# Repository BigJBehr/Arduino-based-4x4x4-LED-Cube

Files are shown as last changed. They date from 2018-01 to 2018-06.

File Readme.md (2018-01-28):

# Arduino based 4x4x4 LED Cube
This project is for a 4x4x4 cube of APA106 tri-color, addressable LEDs. The code was developed using the Arduino IDE. The Adafruit NeoPixel Arduino library and the Arduino Encoder library are required. You can install both libraries using the Library Manager in the Arduino IDE.

The code is for a project that was developed for the Arduino contest on the Instructables web site. There you can find detailed instuctions on how to assemble one for yourself. Follow this link; https://www.instructables.com/id/Cubic_Art/.

# The CubeObject folder has all of the Arduino source files. 
The project was written in C++. Each class used has its own files (.cpp & .h).

# The 3D Parts folder has the OpenSCAD source files and .STL files of all of the 3D printed parts of the project. 
The files are;
    LedCubeJig.stl file is used to 3D print a bending/soldering jig for bending the leads of the LEDs and soldering them together to made the layers of the LED cube.
    spacer.stl file is used to 3D print the spacers that are used to hold the LED layers together while you solder the buses.
    All.stl file is used to 3d print all of the parts for the LED cube.
    Bottom.stl is for 3D printing just the base or bottom of the LED cube.
    Top.stl is for 3D printing the top of the LED cube and the four LED cube holders.
    Knob.stl will 3D print a knob for the rotary encoder in the shape of an orb.

The LedCub.scad file has selections that can be set to true or false to determine what type of Arduino you are using (R3 compatible, ProMini or Nano), what type of USB socket is used and wheather you require a power switch or not. The file usses the software decorator patttern to create the top and base of the LED cube.

# The Diagrams folder has PDF wiring diagrams and a drawing you can print to help make a jig for soldering the LEDs into the layers that make up the cube.
 The preffered mthod is to use the 3D printed jig, but not everyone has access to a 3D printer. The wiring diagram to use is based on the Arduino type and how you choose to use it.
    Nano Wiring .pdf
    R3 Wiring.pdf
    Wiring.pdf
    SpacingJig.pdf is for making a paper diagram for building a soldering jig out of a block of wood.

Enjoy

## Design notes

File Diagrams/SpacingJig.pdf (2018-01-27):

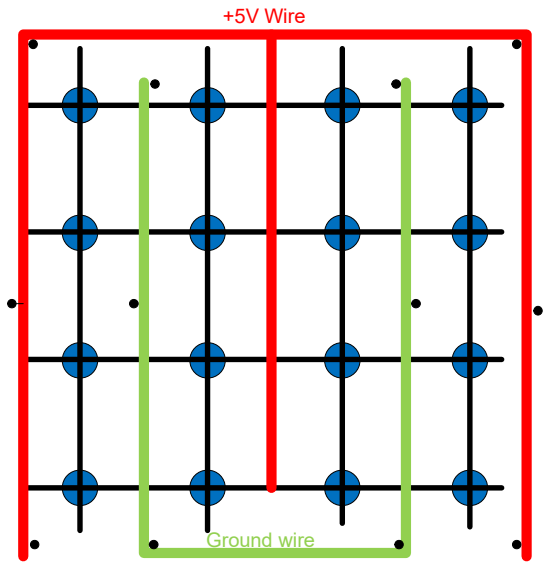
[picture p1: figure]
+5V Wire; Ground wire

# Front

Drill 5mm (7/32) holes in the center of the blue circles.

Bend a piece of the bare 22 awg wire to make the +5V Wire around the outside.

Add a piece of bare 22 awg wire down the center as shown. Solder it to the outside +5V Wire.

Bend a piece of the bare 22 awg wire to make the inner Ground Wire. The Ground Wire should be centered between the LEDs.

Note: Do not put the +5V and Ground Wires up against the LEDs. Leave some space for the LEDs on the ends to connect to each other.

# LED Spacing and Wiring Jig

Driving brads or nails in where the black circles are will aide in bending the 22 awg wires and help to keep them in place. Cut the heads off the nails after driving them in, leaving about ¼” exposed.

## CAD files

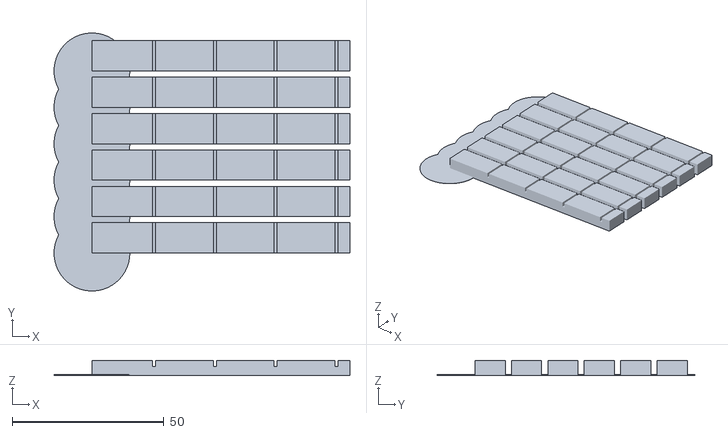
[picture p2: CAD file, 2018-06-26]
3D Parts/LedCubeSpacers.stl
97.5 x 85.0 x 5.00

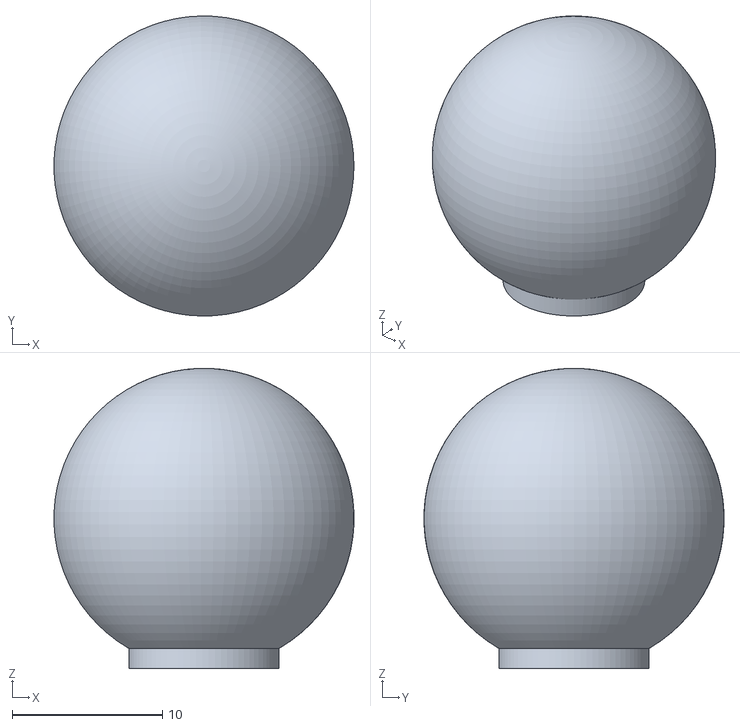
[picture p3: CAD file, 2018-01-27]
3D Parts/Knob.stl
20.0 x 20.0 x 20.0

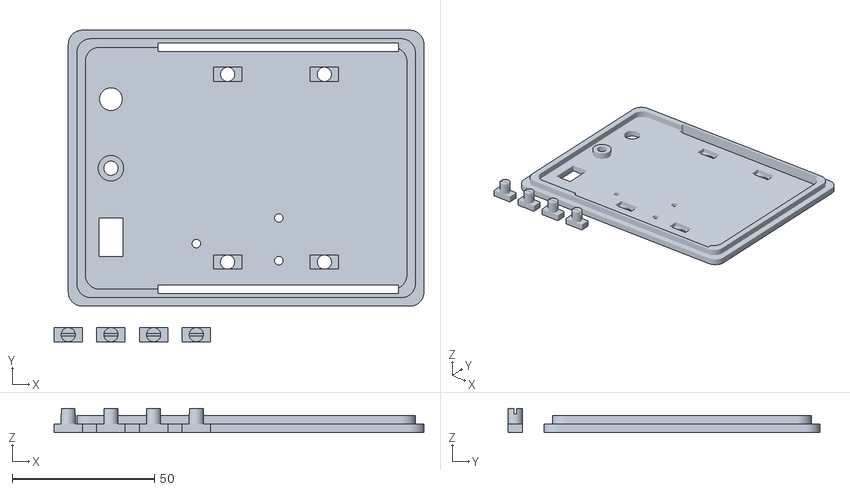
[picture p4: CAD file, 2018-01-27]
3D Parts/Top.stl
130.0 x 109.5 x 8.50

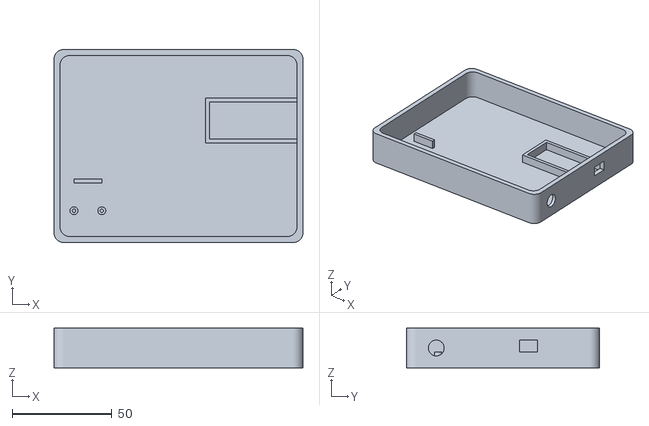
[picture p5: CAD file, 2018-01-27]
3D Parts/Bottom.stl
125.0 x 97.0 x 20.0

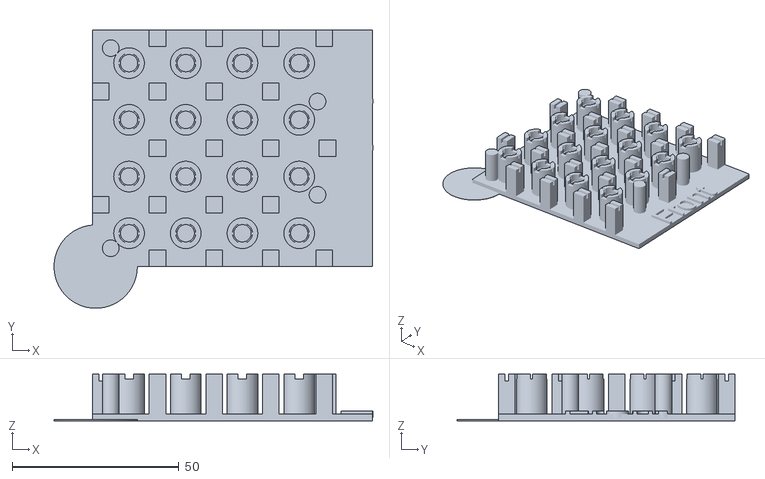
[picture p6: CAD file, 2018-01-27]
3D Parts/LedCubeJig.stl
95.6 x 83.5 x 14.0

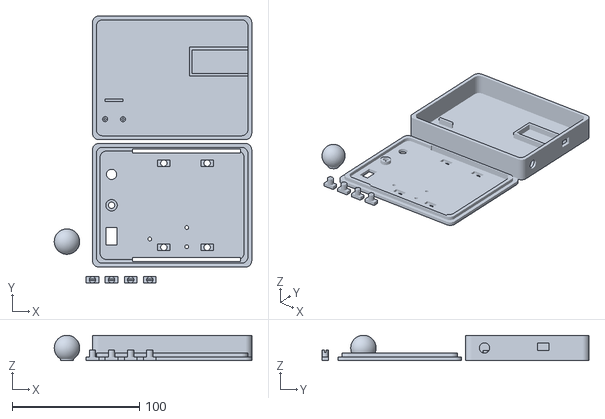
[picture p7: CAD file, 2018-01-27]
3D Parts/All.stl
155.0 x 209.5 x 20.0

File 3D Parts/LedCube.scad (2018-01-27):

// 4x4x4 LED Cube 3D printed parts
// All of the parts are made by this file.
// The Base is a rectangle with rounded corners that houses an Arduino
// The Top fits into the base.
// The knob is for the rotary encoder shaft

// #2 x 1/4" pan head wood screws are used to hold the rotary encode and
// the Arduino R3 boards in place.

// Double sticky tape 1/16" (1.5mm) thick is used to hold the Arduino ProMini and
// nano in place.

// Baseball display case top is press fit.

// Case top is press fit into case base.

// select your Arduino by setting it to true
// only one selection can be true.
ArduinoR3 = false;     // Uno or Leonardo
ProMini = true;
Nano = false;

// make this true if your Arduino board uses a micro USB connector
MicroUSB = true;

// Select what parts to 3D print. Set to true to print a part.
// You can print all three at once or each one at a time.
PrintTop = true;
PrintBase = true;
PrintKnob = true;

// Make this false to remove the power switch.
PowerSwitch = true;

//==================================================================================

X = 125;
Y = 97;
Z = 20;
Radius = 10;
Wall = 3;

RotaryEncoderHeight = 5;

SHD_2_56 = 1.75;         // correct size for #2 pan tapping screw
SHD_M2_5 = 2.25;         // correct size for M2.5 pan tapping screw or tap
SHD_M3 = 2.75;           // correct size for M3 pan tapping screw or tap

// Baseball display case cover
BBLip2Lip = 85;
BBLipWidth = 3;
BBLipLength = 84.5;
BBLipDepth = 6;
BBTopX = 89;
BBTopY = BBLip2Lip + BBLipWidth;

ArduinoBossH = 5;

// Arduino R3 mounts 19mm from the inside back wall
R3XOffset = 19;


// Arduino R3 boards have a power jack. The circuitry on the Arduino board
// cannot handle the load of the LED cube (4A). If you wish to use the onboard
// power jack then you must solder wires to the power jack on the bottom of the
// board to run power to the LED cube. If you do this then you do not need the 
// power switch on the top.

ArduinoXOffset = R3XOffset;
// uncomment this offset to hide the Arduino's power jack
//ArduinoXOffset = 19 + Wall;


// Arduino Pro Mini Dimensions
ProMiniX = 44;
ProMiniY = 18.5;
ProMiniZ = 5;

// Arduino Nano Dimensions
NanoX = 18.75;
NanoY = 34.5;
NanoZ = 3;

//===== main =======================================================================
$fn = 50;

if (PrintTop)
{
    DecoratedTop();
    
    for(x = [0:15:45])
        translate([x, -10, 0]) LedCubeMount(0);
}

if (PrintBase)
{
    if (PrintTop)
    {
        translate([0, Y + 3, 0]) DecoratedBase();
    }
    else
    {
        DecoratedBase();
    }
}

if (PrintKnob)
{
    translate([-20, 20, 0]) Knob();
}

//===== Top Level Parts ============================================================

// Top with cutouts for the power switch, mode LED, rotary encoder,
// baseball case and LED cube mounts
module DecoratedTop()
{
    yoff1 = Y / 4;
    yoff2 = Y / 2;
    yoff3 = yoff1 + yoff2;

    // center the baseball display case cover
    bby = (Y - BBTopY) / 2;
    bbx = X - (BBTopX + bby);

    difference()
    {
        union()
        {
            translate([Radius / 2, Radius / 2, 0]) Top();
            
            // add mode LED holder
            translate([Wall + 12, yoff2, 0]) cylinder(d = 9, h = 2 * Wall);
        }   //  union
        
        // add rotaty encoder on top (shaft hole)
        translate([Wall + 12, yoff3, 0]) RotaryEncoder();
        
        // add mode LED top
        translate([Wall + 12, yoff2, 0]) cylinder(d = 5, h = 2 * Wall);
        
        if (PowerSwitch)
        {
            // add the power switch cutout on top
            translate([Wall + 12, yoff1, 0]) RockerSw();
        }
        
        // center the baseball display case cover
        translate([bbx, bby, 0]) BBTopSlots();
        
        // LED Cube wires
        LedCubeWires();
        
        // center the LED cube
        translate([56, (Y - 66) / 2, 4]) rotate([180, 0, 0]) LedCubeMounts(1);
    }   //  difference
}   //  DecoratedTop


// features are added to the basic base
module DecoratedBase()
{
    yoff1 = Y / 4;
    yoff2 = Y / 2;
    yoff3 = yoff1 + yoff2;

    if (ArduinoR3)
    {
        // Arduino R3 (Uno or Leonardo)
        yuno = Y - ((Y - 53) / 2);
        extraZ = 10;
        
        difference()
        {
            union()
            {
                // align base with axis
                translate([Radius / 2, Radius / 2, 0]) Base(Z + extraZ);
        
                // standard Arduino Uno R3 hole pattern
                translate([X - ArduinoXOffset, yuno, 1]) rotate([0, 0, 180]) R3Bosses(6);
            }   //  union
            
            // cutouts in the back wall for the Uno powerjack and USB-B connector
            // Uno mounting bosses
            translate([X - ArduinoXOffset, yuno, 1]) rotate([0, 0, 180])
            {
                UnoBosses(SHD_M3);
                if (ArduinoXOffset == R3XOffset)
                {
                    R3PowerJack();
                }

                if (MicroUSB)
                {
                    MicroUsb();
                }
                else
                {
                    R3Usb();
                }
            }
            
            if (ArduinoXOffset != R3XOffset)
            {
                // add power jack to back panel
                PowerJack(X - 12, 15, (Z + extraZ)/ 2);
            }
                

        }   //  difference
    
        // add rotaty encoder bosses
        translate([Wall + 12, yoff1, Wall]) RotaryEncoderBosses(RotaryEncoderHeight + extraZ);
    }
    else
    {
        // not an Arduino R3
        difference()
        {
            // align base with axis
            translate([Radius / 2, Radius / 2, 0]) Base(Z);
            
            // add power jack to back panel
            PowerJack(X - 12, 15, Z / 2);
            
            // Arduino Pro Mini has a Mini USB connector
            if (ProMini)
            {
                translate([X - ProMiniX - 5, 50, Wall]) ProMiniUsb();
            }
        }   //  difference
        
        // add rotaty encoder bosses
        translate([Wall + 12, yoff1, Wall]) RotaryEncoderBosses(RotaryEncoderHeight);
        
        if (ProMini)
        {
            translate([X - ProMiniX - Wall - 2, 50, Wall]) ProMiniMount();
        }

        if (Nano)
        {
            translate([60, (Y - (NanoY + 4)) / 2, Z - NanoZ - Wall]) NanoMount();
        }
    }
}   //  DecoratedBase

// Rotary Encoder Ball Knob
module Knob()
{
    od = 10;
    z = 15;

    $fn = 75;
    difference()
    {
        union()
        {
            translate([0, 0, od]) sphere(od);
            cylinder(d = od, h = 5);
        }
        DHole(z);
    }
}   //  Knob

//===== Various Building Blocks ====================================================

// basic base, a hollow block with rounded corners
module Base(z)
{
    difference()
    {
        minkowski()
        {
            cube([X - Radius, Y - Radius, z / 2]);
            cylinder(d = Radius, h = z / 2);
        }   // minkowski
        
        // hollow it out
        translate([Wall, Wall, Wall]) minkowski()
        {
            cube([X - Radius - Wall - Wall, Y - Radius - Wall - Wall, (z / 2) - Wall]);
            cylinder(d = Radius, h = (z / 2));
        }   // minkowski
    }   // difference
}   //Base

// Top fits into the base
module Top()
{
    z = Wall;
    translate([0, 0, 0]) minkowski()
    {
        cube([X - Radius, Y - Radius, z / 2]);
        cylinder(d = Radius, h = z / 2);
    }   // minkowski
        
    translate([Wall, Wall, Wall]) difference()
    {
        minkowski()
        {
            cube([X - Radius - (2 * Wall), Y - Radius - (2 * Wall), (z / 2)]);
            cylinder(d = Radius, h = z / 2);
        }   // minkowski
        
        // hollow it out
        translate([Wall, Wall, 0]) minkowski()
        {
            cube([X - Radius - (4 * Wall), Y - Radius - (4 * Wall), (z / 2)]);
            cylinder(d = Radius, h = z / 2);
        }   // minkowski
    }   // difference
}   //  Top

//===== Arduino mounts =====

// uses double stick tape to hold it in place
module ProMiniMount()
{
    difference()
    {
        cube([ProMiniX + 2, ProMiniY + 4, ProMiniZ]);
        translate([2, 2, 0]) cube([ProMiniX, ProMiniY, ProMiniZ]);
    }
       
}   //  ProMiniMount

module ProMiniUsb()
{
    usbx = Wall + 5;
    usby = 9;
    usbz = 6;
    
    translate([ProMiniX + 2, (ProMiniY + 4 - usby) / 2, ProMiniZ]) cube([usbx, usby, usbz]);
}   //  ProMiniUsb

// uses double stick tape to hold it in place
module NanoMount()
{
    difference()
    {
        cube([NanoX + 4, NanoY + 4, NanoZ]);
        translate([2, 2, 0]) cube([NanoX, NanoY, NanoZ]);
    }
}   //  NanoMount

// Arduino Uno R3 & Leonardo
// uses #2x1/4" pan head, wood screws
module R3Bosses(d)
{
    x = 52.25;
    y = 48.75;
    z = 5;

    cylinder(d = d, h = ArduinoBossH); 
    translate([1.5, y, 0]) cylinder(d = d, h = ArduinoBossH);
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

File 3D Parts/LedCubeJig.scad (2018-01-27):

// 4x4x4 LED Cube LED Soldering Aides

Led2Led = 17;

X = 3 * Led2Led;
Y = X;
Z = 2;

LedD = 5.2;
LedRing = 6;
BossD = LedD + 4;   // leaves 2mm
BossZ = 12;
Leads = 1.27;
LeadW = .6;
Wire = 1;           // sized for 22awg bare wire
WireZ = BossZ - 1.5;
SupportW = 5;

$fn = 50;
BendingJig();
LayerSpacers(70);

module LayerSpacers(yoffset)
{
    for(y = [0: 12: 60])
    {
        translate([0, y + yoffset, 0]) LayerSpacer();
    
        // easy removal tab
        translate([0, y + yoffset, 0]) cylinder(d = 25, h = .4);
    }
}   //  LayerSpacers

module LayerSpacer()
{
    x = 85;
    y = 10;
    difference()
    {
        cube([x, y, 5]);
        for(i = [20: 20: x])
            translate([i, 0, 3]) cube([Wire, y, 2]);
    }
}   //  LayerSpacer

module BendingJig()
{
    translate([-11, -10, 0]) cube([84, 71, Z]);
    Bosses();
    Supports();
    translate([73, 9, Z])
        linear_extrude(height = 2, center = true, convexity = 10, twist = 0)
            rotate([0, 0, 90]) text("Front");

    // easy removal tab
    translate([-10, -10, 0]) cylinder(d = 25, h = .4);
}   //  BendingJig

module Bosses()
{
    for(y = [0: Led2Led: Y])
        for(x = [0: Led2Led: X])
            translate([x, y, Z]) Boss();
}   //  Bosses

module Boss()
{
    difference()
    {
        cylinder(d = BossD, h = BossZ);
        cylinder(d = LedD, h = BossZ);
        translate([0, 0, BossZ - 3]) cylinder(d = LedRing, h = BossZ);

        translate([-BossD / 2, -LeadW / 2, WireZ]) cube([BossD, LeadW, 3]);
        translate([-Leads, -BossD / 2, WireZ]) cube([2 * Leads, BossD, 3]);
    }
}   //  Boss

module Supports()
{
    i = (Led2Led - SupportW) / 2;

    // inner supports
    for(y = [i: Led2Led: Y])
        for(x = [i: Led2Led: X])
            translate([x, y, Z]) Support(0);

    // left side power supports
    y = -(2 * SupportW);
    for(x = [i: Led2Led: X])
        translate([x, y, Z]) Support(0);
    
    // right side power supports
    y1 = Y + SupportW;
    for(x = [i: Led2Led: X])
        translate([x, y1, Z]) Support(0);

    // back side power supports
    translate([-(SupportW + 1), i, Z]) rotate([0, 0, 90]) Support(0);
    translate([-(SupportW + 1), i + 2 * Led2Led, Z]) rotate([0, 0, 90]) Support(0);
/*
    for(y = [i: Led2Led: Y])
    {
        translate([-(SupportW + 1), y, Z]) rotate([0, 0, 90]) Support(0);
    }
*/    
    // front side ground support
    translate([X + SupportW + 1, Led2Led + (2 * SupportW) + 1, Z]) rotate([0, 0, 270]) Support(0);

    
    // bending posts
    translate([-5.5, -4.5, Z]) cylinder(d = SupportW, h = BossZ);
    translate([-5.5, X + 4.5, Z]) cylinder(d = SupportW, h = BossZ);

    translate([X + 5.5, Led2Led - 5.5, Z]) cylinder(d = SupportW, h = BossZ);
    translate([X + 5.5, (2 * Led2Led) + 5.5, Z]) cylinder(d = SupportW, h = BossZ);

    
    translate([X + SupportW, -10, Z]) Support(0);
    translate([X + SupportW, X + SupportW, Z]) Support(0);
    
    // paths
//    z1 = 3;
//    translate([-6.5, -(6 + ((SupportW - Wire) / 2)), 10]) cube([70, Wire, z1]);
}   //  Supports

module Support(type)
{
    notchz = 3;
    z = WireZ - 0.5;
    difference()
    {
        cube([SupportW, SupportW, BossZ]);
        translate([0, (SupportW - Wire) / 2, z]) cube([SupportW, Wire, notchz]);
        
        if (1 == type)
        {
            translate([(SupportW - Wire) / 2, 0, z]) cube([Wire, SupportW / 2, notchz]);
        }
        
        if (2 == type)
        {
            translate([(SupportW - Wire) / 2, 0, z]) cube([Wire, SupportW, notchz]);
        }
    }
}   //  Support

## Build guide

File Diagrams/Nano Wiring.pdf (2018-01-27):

## LED Cube Wiring Diagram

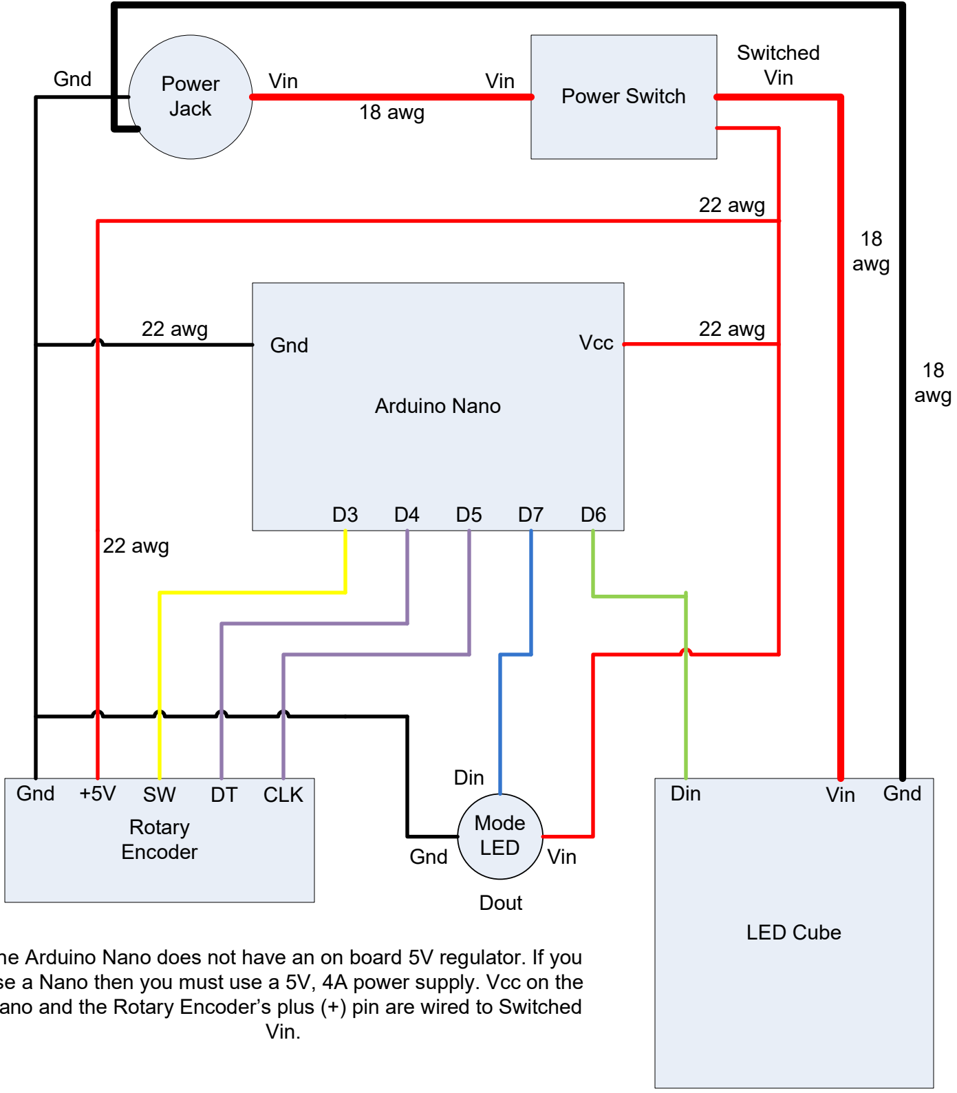
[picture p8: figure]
Power; Jack; Power Switch; Arduino Nano; Rotary Encoder; Mode LED; LED Cube; Din; Gnd +5V; Vcc; DT CLK; Gnd; Vin; Switched; Dout; Vin.; 18 awg; 22 awg

The Arduino Nano does not have an on board 5V regulator. If you use a Nano then you must use a 5V, 4A power supply. Vcc on the Nano and the Rotary Encoder’s plus (+) pin are wired to Switched

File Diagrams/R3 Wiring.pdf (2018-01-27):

## LED Cube Wiring Diagram for using the Built-in Power Jack

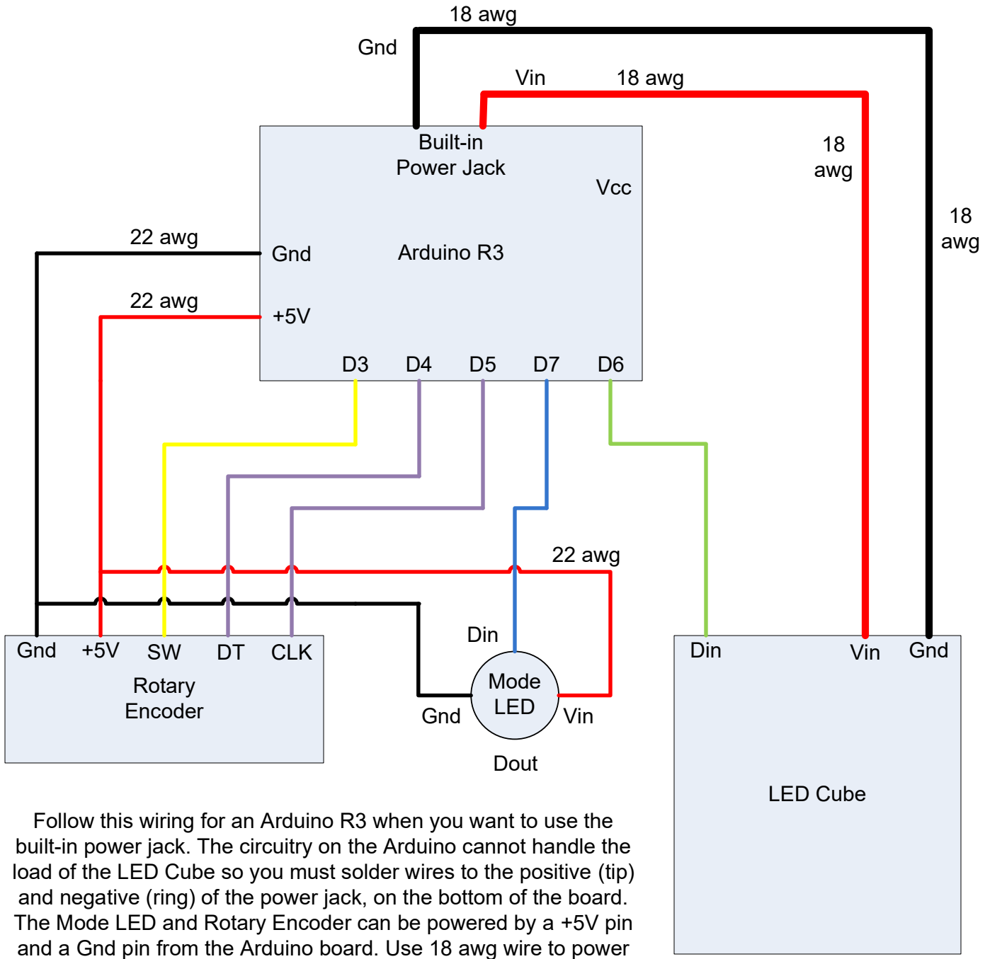
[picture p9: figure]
Arduino R3; Rotary Encoder; Mode LED; LED Cube; Din; Gnd +5V; Vcc; DT CLK; Gnd; Vin; Dout; 18 awg; 22 awg; Built-in Power Jack

Follow this wiring for an Arduino R3 when you want to use the built-in power jack. The circuitry on the Arduino cannot handle the load of the LED Cube so you must solder wires to the positive (tip) and negative (ring) of the power jack, on the bottom of the board. The Mode LED and Rotary Encoder can be powered by a +5V pin and a Gnd pin from the Arduino board. Use 18 awg wire to power the LED cube. All other wiring uses 22-28 awg wire.

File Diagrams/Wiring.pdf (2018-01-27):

## LED Cube Wiring Diagram

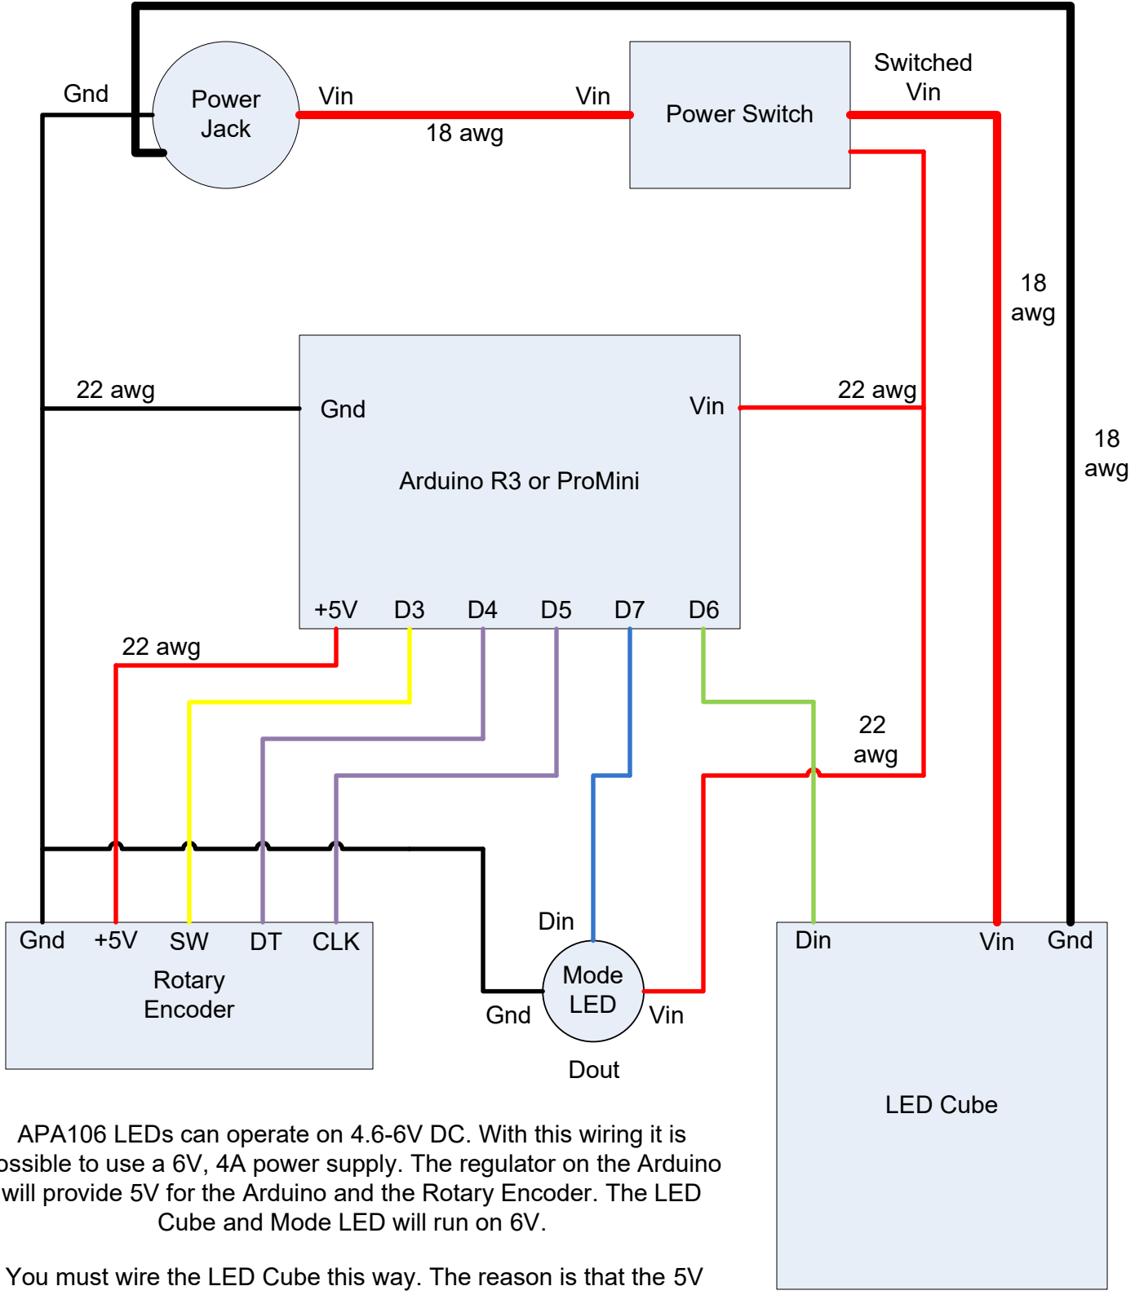
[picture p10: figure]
Power; Jack; Power Switch; Arduino R3 or ProMini; Rotary Encoder; Mode LED; LED Cube; Din; Gnd +5V; Vin; DT CLK; Gnd; Switched; Cube and Mode LED will run on 6V.; Dout; 18 awg; 22 awg

APA106 LEDs can operate on 4.6-6V DC. With this wiring it is possible to use a 6V, 4A power supply. The regulator on the Arduino will provide 5V for the Arduino and the Rotary Encoder. The LED

You must wire the LED Cube this way. The reason is that the 5V regulator on the Arduino cannot provide enough current to run the 64 LEDs in the cube.

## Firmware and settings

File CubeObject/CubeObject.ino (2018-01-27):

// Project:  4x4x4 Cube of APA106 addressable LEDs.
// Author:   James R. Behrens
// Compiler: Arduino 1.8.5
// Target:   Arduino Mini, AtMega 328P
// 10-07-17
//==============================================================================
// The LEDs are wired as a continuous strip of 64 LEDs. The LEDs are arranged
// into four layers of 16 LEDs each. Every other layer is reversed. Every other
// row is reversed.

// The number represents the LED position in the strip, The layers are;
//---- Layer 0 ---- + ---- Layer 1 ---- + ---- Layer 2 ---- + ---- Layer 3 ----
//  3,  4, 11, 12   |   28, 27, 20, 19  |   35, 36, 43, 44  |   60, 59, 52, 51
//  2,  5, 10, 13   |   29, 26, 21, 18  |   34, 37, 42, 45  |   61, 59, 52, 51
//  1,  6,  9, 14   |   30, 25, 22, 17  |   33, 38, 41, 46  |   62, 57, 54, 49
//  0,  7,  8, 15   |   31, 24, 23, 16  |   32, 39, 40, 47  |   63, 56, 55, 48

// The AtMega328P only has 2KB of RAM. To avoid using up all the RAM, all of
// maps and initializers have been moved to Flash memory. Special functions
// are used to move the data from Flash to RAM.

// The maps are indexed by the current position of an LED. The value returned
// is the new position of the LED.

// A rotary quadrature encoder is used to set the speed of the sprites. The
// encoder is wired such that a clockwise rotation increases the speed of the
// sprites (decrease Speed to increase sprite speed).
// CLK -> pin 5, DT -> pin 4, SW -> pin 3

// This project uses object oriented coding.
//==============================================================================
#include <Adafruit_NeoPixel.h>
#include <Encoder.h>
#include <avr/pgmspace.h>

//#include "CubeObject.h"     // common definitions
#include "ActionContinuous.h" // ActionCotinuous class definitions
#include "ActionYaw.h"        // ActionYaw class definitions
#include "ActionPitch.h"      // ActionPitch class definitions
#include "ActionRoll.h"       // ActionRoll class definitions
#include "ActionSlide.h"      // ActionSlide class definitions
#include "ActionRandom.h"     // ActionRandom class definitions
#include "ActionBrighten.h"   // ActionBrighten class definitions


#define NUMACTIONS    7

#define SWPIN       3           // rotary encoder pins
#define DTPIN       4
#define CLKPIN      5
#define LEDPIN      6           // I/O pin the Cube is wired to
#define MODELEDPIN  7           // mode indicator pin

#define DBGLED      13    // debug LED

#define RANDOMTIME    16
#define RANDOMDELAY   1000

#define SWMASK        0x00000FFF
enum
{
  NOMODE = 0,
  SPEEDMODE,
  BRIGHTMODE
};

//***** Ram Variables *****
int       LoopDelay = 1;
int       LoopTimer = 10;
int       Index = 0;
int       Speed = 100;
Action    *pAction;
Action    *pActions[NUMACTIONS];
uint32_t  debounce = 0;
bool      flag = false;

// This configuration works for APA106 LEDs.
// LED cube object
Adafruit_NeoPixel Leds = Adafruit_NeoPixel(NUMLEDS, LEDPIN, NEO_RGB + NEO_KHZ800);
// mode LED object
Adafruit_NeoPixel ModeLed = Adafruit_NeoPixel(1, MODELEDPIN, NEO_RGB + NEO_KHZ800);
// decrease means the sprites move faster, increase moves the sprites slower
Encoder SpeedEnc(CLKPIN, DTPIN);

// The cube as an array of APA106 LEDs
Apa106_t  Cube[NUMLEDS];

Sprite_t sprites[MAXSPEITES];

int32_t oldPosition  = -999;
byte    swmode = NOMODE;
int     Brightness = 32;

//******************************************************************************
// Pin 13 has has the built-in LED.
// Pin 3 is the rotary encoder switch input
// Pin 4 is the rotary encoder DT input
// Pin 5 is the rotary encoder CLK input
// Pin 6 is the APA106 LED cube output pin 
// Pin 7 is the APA106 Mode LED output pin
//******************************************************************************
void setup()
{
  pinMode(DBGLED, OUTPUT);
  digitalWrite(DBGLED, LOW);
  
  pinMode(SWPIN, INPUT_PULLUP);

  Serial.begin(115200);

  randomSeed(analogRead(0));
  
  Leds.begin();
  ModeLed.begin();

  // turn off all LEDs
  ModeLed.setPixelColor(0, 0, 0, 0);
  fillCube(0);
  showCube();

  // allocate an array of pointers to each instansiated Action
  pActions[0] = new ActionContinuous();
  pActions[1] = new ActionYaw();
  pActions[2] = new ActionPitch();
  pActions[3] = new ActionRoll();
  pActions[4] = new ActionSlide();
  pActions[5] = new ActionRandom();
  pActions[6] = new ActionBrighten();

  // setup first action
  selectAction();

  delay(100);
} //  Setup

//******************************************************************************
// Fill the cube with a single color.
//******************************************************************************
void fillCube(uint32_t color)
{
  for (int i = 0; i < NUMLEDS; i++)
    Cube[i].color = color;
} //  fillCube

//******************************************************************************
// Transfer the contents of the Cube to the NeoPixel buffer and display it.
//******************************************************************************
void showCube()
{
  for (int i = 0; i < NUMLEDS; i++)
    Leds.setPixelColor(i, Cube[i].rgb.red, Cube[i].rgb.green, Cube[i].rgb.blue);

  Leds.show();
} //  showCube

//******************************************************************************
// Select the next action from the array of actions.
//******************************************************************************
void selectAction()
{
  pAction = pActions[Index];
  pAction->setTimer(Speed);
  pAction->setBrightness(Brightness);
  pAction->start(sprites);
  Index++;
  Index %= NUMACTIONS;
} //  selectAction

//******************************************************************************
//******************************************************************************
void loop()
{
  int32_t newPosition, change;
  
  if (pAction->runTimer())
  {
    pAction->setTimer(Speed);
    pAction->setBrightness(Brightness);

    // blank the cube
    fillCube(0);
  
    // add all sprites to the cube
    pAction->addSprites();

    // show the cube
    showCube();

    // move all sprites
    pAction->moveSprite();

    if (pAction->isDone())
        selectAction();
  }

  delay(LoopDelay);

  // check the rotary encoder
  newPosition = SpeedEnc.read();
  if (newPosition != oldPosition)
  {
    change = newPosition - oldPosition;
    oldPosition = newPosition;

    switch(swmode)
    {
      case NOMODE:
        break;
      case SPEEDMODE:
        Speed += change;
        if (Speed < 1)
          Speed = 1;
        break;
      case BRIGHTMODE:
        Brightness -= change;
        if (Brightness > 255)
          Brightness == 255;
  
        if (Brightness < 1)
          Brightness = 1;
          break;
    } //  switch
  }

  debounce <<= 1;
  debounce |= digitalRead(SWPIN) & 0x00000001;
  if ((0 == debounce & SWMASK))
  {
    if (flag)
    {
      digitalWrite(DBGLED, HIGH);
      flag = false;
      swmode++;
      if (swmode > BRIGHTMODE)
        swmode = NOMODE;
    }
  }
  else if (SWMASK == debounce & SWMASK)
  {
    flag = true;
    digitalWrite(DBGLED, LOW);
  }

  switch(swmode)
  {
    case NOMODE:
      ModeLed.setPixelColor(0, 0, 0, 0);
      ModeLed.show();
      break;
    case SPEEDMODE:
      // red for SPEEDMODE
      ModeLed.setPixelColor(0, 32, 0, 0);
      ModeLed.show();
      break;
    case BRIGHTMODE:
      // green for BRIGHTNESSMODE
      ModeLed.setPixelColor(0, 0, 32, 0);
      ModeLed.show();
      break;
  } //  switch

} //  Loop

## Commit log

2018-01-27 Initial code drop
    initial file release
    [All.stl, Bottom.stl, Knob.stl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]
2018-06-26 Added missing LedCubeSpacers.stl
    Removed wrong spacers.stl file and added correct LedCubeSpacers.stl file
    [LedCubeSpacers.stl, spacer.stl]
